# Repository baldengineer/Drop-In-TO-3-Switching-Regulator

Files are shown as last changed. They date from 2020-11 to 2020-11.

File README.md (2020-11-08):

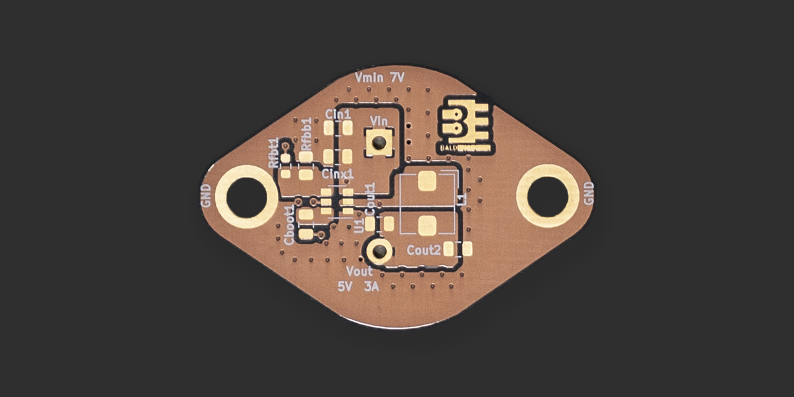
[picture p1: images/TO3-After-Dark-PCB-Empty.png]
after dark pcb of a to3 shaped board

## Drop-In TO-3 Switching Regulator
KiCad design files for LM323 Linear regulator replacement for 5 volt applications. Created using KiCad 5.x.

Replaces the 5 volt output, LM323 linear regulator available in a TO-3 package. This regulator was found in the first revision of the Commodore VIC-20. The switching regulator generates significantly less heat than the original linear supply.

Based on a TI [https://www.ti.com/store/ti/en/p/product/?p=TPS563240DDCR](TPS563240DDCR). Capable of supplying up to 3 Amps at 5 volts. 

At 3 amps output, the output ripple is less than 50 mVpp. (Less than 30 mVpp when measurement is band-limited to 20 MHz!)

## Input
Input voltage was only tested with about 9 volts, from the VIC-20's rectified AC input. According to its datasheet, it can operate up to 17 volt in. However, watch the voltage rating of the input capacitors. 

## Output
The TPS563240 has an adjustable output. This design used fixed resistors for a fixed 5.0 volt output. 

## Ground
Ground is connected with the plated-through holes.

## Heat Sink
There are no provisions for direct metal contact to heat-sink the board. With 9 volt in, 3 Amp out, and open air in an ambient of 22C, the hottest component was the inductor at 55C. 

At 1.5 amps or less, the heat rise for the total board is about 5C.

## Bald Engineer on Twitch
This board was designed, built, and tested live with the Bald Engineer. Check out his electronics live stream at: [https://twitch.tv/baldengineer](https://twitch.tv/baldengineer).

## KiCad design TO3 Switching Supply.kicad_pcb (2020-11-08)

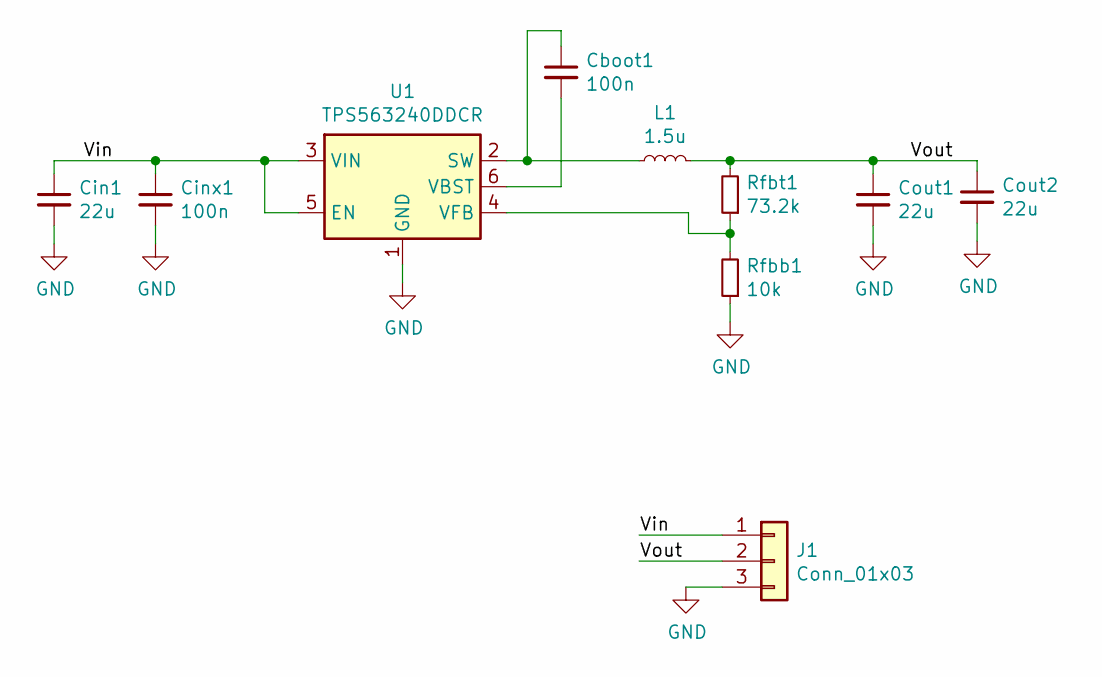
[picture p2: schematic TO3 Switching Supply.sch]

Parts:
Cboot1: 100n; C_0805_2012Metric
Cin1: 22u; C_0805_2012Metric
Cinx1: 100n; C_0805_2012Metric
Cout1, Cout2: 22u; C_0805_2012Metric
J1: Conn_01x03; TO-3-withEdgeCuts
L1: 1.5u; L_Bourns_SRP5030T
Rfbb1: 10k; R_0805_2012Metric
Rfbt1: 73.2k; R_0603_1608Metric
U1: TPS563240DDCR; SOT-23-6

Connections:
/Vin: Cin1.1, Cinx1.1, J1.1, U1.3 (VIN), U1.5 (EN)
/Vout: Cout1.1, Cout2.1, J1.2, L1.2, Rfbt1.2
GND: Cin1.2, Cinx1.2, Cout1.2, Cout2.2, J1.3, Rfbb1.1, U1.1 (GND)
unnamed: Cboot1.1, L1.1, U1.2 (SW)
unnamed: Cboot1.2, U1.6 (VBST)
unnamed: Rfbb1.2, Rfbt1.1, U1.4 (VFB)

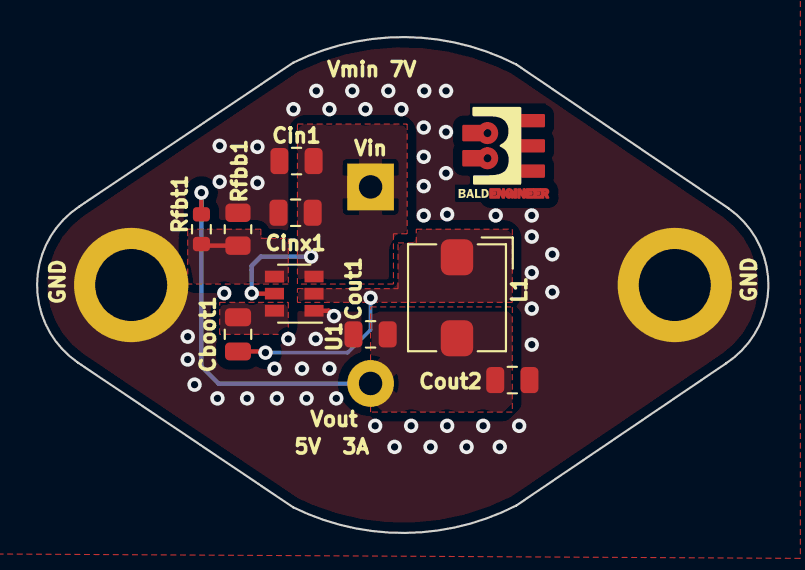
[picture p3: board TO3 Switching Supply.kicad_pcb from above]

Board: 2 copper layers, 40.6 x 27.5 mm, 11 parts (0 on the bottom side), 6 nets.

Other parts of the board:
svg2mod: G***; BE5
